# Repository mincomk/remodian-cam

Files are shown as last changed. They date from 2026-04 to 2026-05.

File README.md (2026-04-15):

# Remodian CAM

I've worked in a project called [Remodian](https://github.com/mincomk/remodian), which is a simple IR-Web bridge for Meridian speakers.

## The Problem

Previous Remodian was only capable to control the volume up and down, by one tick. So there was no way to know what the current volume level was, and it was impossible to set a specific volume level.

## My Solution
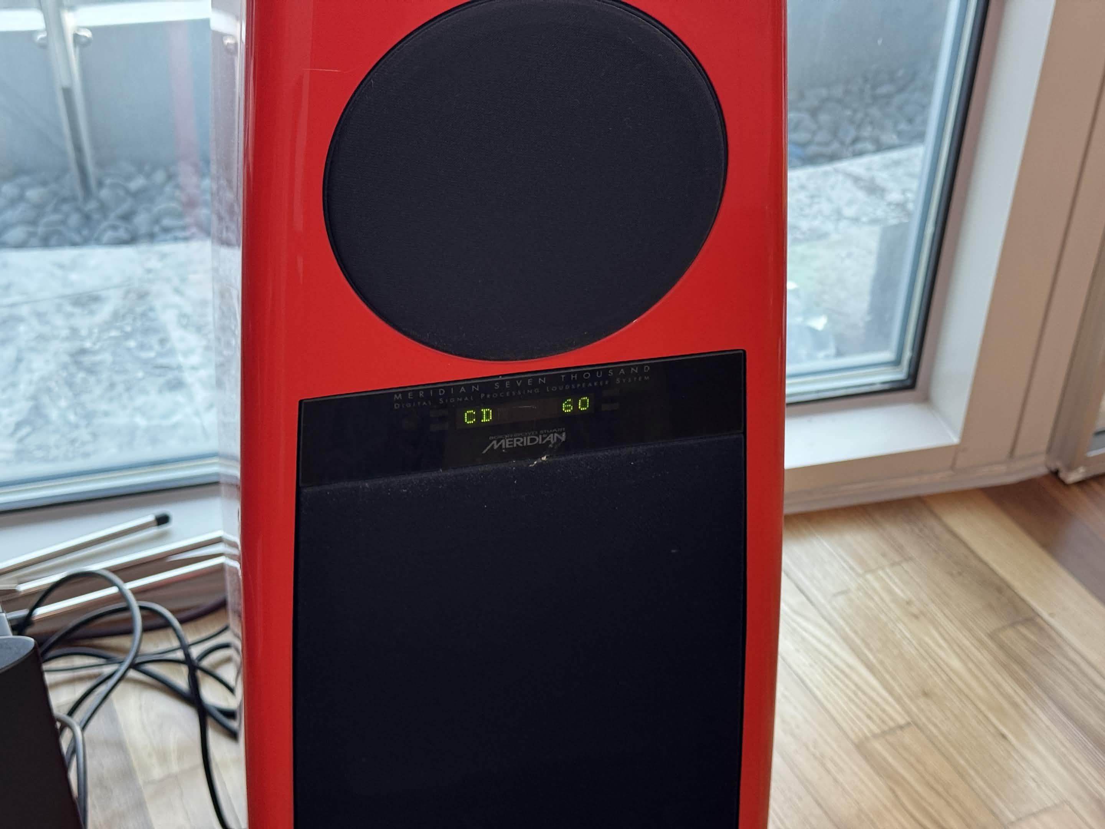
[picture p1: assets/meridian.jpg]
meridian

Unsurprisingly, the speakers have a volume display. Two green numbers showing current volume. So the next task is trivial: Computer Vision + Control System.

## Making ESP32 See the Volume
I noticed that the volume display is simple 5x7 LED grid. And the camera will always be in the same position. So I just divided the image to 5x7 regions, and averaged the pixel values in each region.

Since I could use thresholding to determine whether a region is lit or not, I went other approach: one-hot scoring. I created a template for each digit (0-9) that contains ideal state of each region (i.e. 255 for lit, 0 for unlit). Then I scored the current image against each template, and the one with the highest score is the recognized digit.

This approach avoids the need for thresholding, and is more robust to noise and lighting changes.

I've made a simple GUI tool called `calibration-ui` (`dev/calibration-ui`). This tool captures image from the camera, and allows me to configure perspective transform (i.e. warp crop) of the image. Then it produces standardized *crop string* (`1,1,1,1+1,1,1,1`) that can be used in the backend code to apply the same perspective transform.
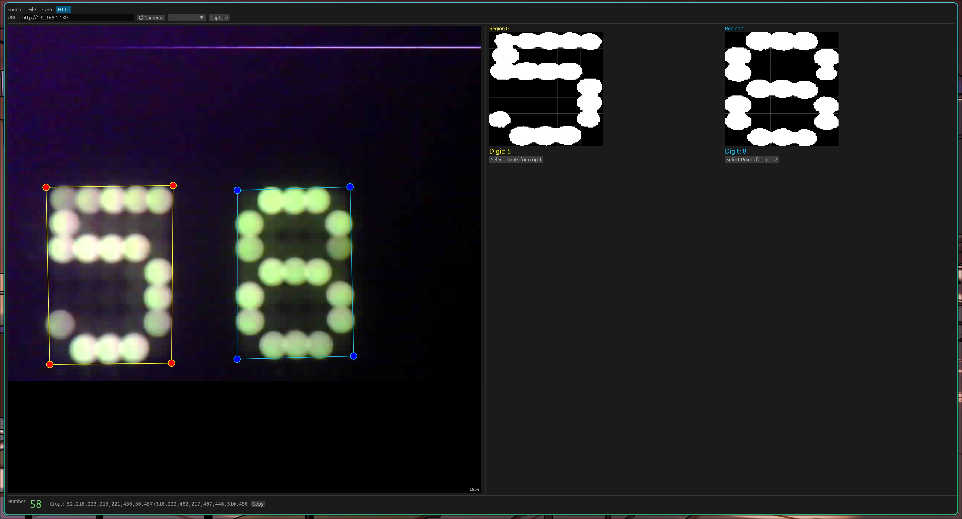
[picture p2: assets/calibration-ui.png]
calibration-ui


## Control System
ESP32 IR blaster firmware accepts four commands: `volume up`, `volume down`, `volume rapid up start`, and `volume rapid up stop`. The first two commands will send one tick of volume up/down, while the last two commands will start/stop sending volume up command repeatedly with a short delay (RC5 IR timeframe).

The control logic is based on a simple bang-bang controller. It separates the difference between current volume and target volume into three zones: **Just Right** (i.e. deadband), **Very Near** (±4.0), **Near** (±8.0), and **Far** (±∞). Depending on which zone the difference falls into, the controller will send different commands to the IR blaster.
- If the difference is in the **Just Right** zone, do nothing.
- If the difference is in the **Very Near** zone, send one tick of volume up/down in slower pace.
- If the difference is in the **Near** zone, send one tick of volume up/down in faster pace.
- If the difference is in the **Far** zone, send rapid volume up/down command.

Also I added a manual control mode, which allows the user to send volume up/down commands directly from the web interface. Web interface also does the rapid command set on long press, and stop on release.

### Problem: ESP32-CAM is slow!
ESP32-CAM is a very cheap and convenient camera module, but it has a very slow processing speed. The image processing takes around 300ms, which is too slow for control system to be responsive.

But we have a helpful trait of the volume here: It changes consistently. So I used linear extrapolation to predict the current volume level based on the last two recognized volume levels and their timestamps. This way, we can get a more responsive control system, even with the slow image processing.

## Conclusion
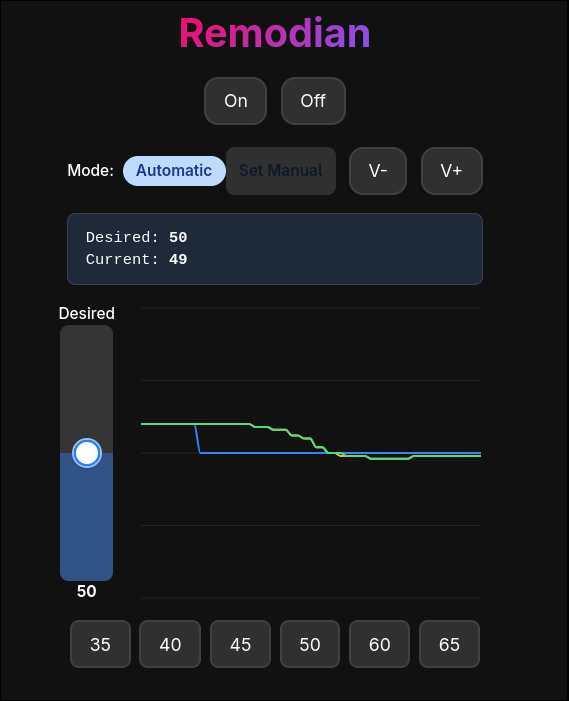
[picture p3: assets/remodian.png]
remodian


LGTM! Let's enjoy the music.

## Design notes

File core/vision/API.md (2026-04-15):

# LCD Pixel Digit Recognition API

This document describes the API for the lcd-pixel digit recognition system.

## Overview

The lcd-pixel system recognizes single digits (0-9) from LCD display images through a processing pipeline that:
1. Loads an image from disk or camera
2. Applies perspective correction to straighten the display
3. Extracts and analyzes the 5×7 segment grid
4. Matches against trained digit templates
5. Returns the detected digit or 0 if the display is empty

## Image Input

### Supported Formats

- **PNG** - Portable Network Graphics (any bit depth)
- **JPEG** - Joint Photographic Experts Group
- **Grayscale** - Single-channel images (typically pre-thresholded)
- **Color** - RGB images (green channel extracted during preprocessing)

### Image Requirements

- **Size**: Arbitrary (will be cropped and resized to 128×128)
- **Quality**: Should contain visible LCD segments
- **Color Space**: RGB or Grayscale (8-bit per channel)

### Input Interface

#### Rust API

```rust
pub trait ImageSource {
    fn width(&self) -> u32;
    fn height(&self) -> u32;
    fn pixel_rgb(&self, x: u32, y: u32) -> (f32, f32, f32);
}
```

**Example: File-based Input**

```rust
use lcd_pixel::preprocess::FileImageSource;

let source = FileImageSource::new("path/to/image.jpg")?;
```

**Future: Camera Input**

The `ImageSource` trait enables camera integration without modifying core code:

```rust
pub struct Ov2640Source {
    buffer: Vec<u8>,
    width: u32,
    height: u32,
}

impl ImageSource for Ov2640Source {
    fn width(&self) -> u32 { self.width }
    fn height(&self) -> u32 { self.height }
    fn pixel_rgb(&self, x: u32, y: u32) -> (f32, f32, f32) {
        // Decode from raw camera buffer
        // Return normalized (r, g, b) in [0.0, 1.0]
    }
}
```

## Crop Points Input

### Purpose

Four perspective corner points define the LCD display region within the image and correct for skew/tilt.

### Format

```
[(u32, u32); 4]
```

Four `(x, y)` coordinate pairs in the **source image coordinate system**.

### Point Order

Points must be provided in a specific order:
1. **Top-left** — upper-left corner of display
2. **Top-right** — upper-right corner of display
3. **Bottom-right** — lower-right corner of display
4. **Bottom-left** — lower-left corner of display

```
(0,0)              (127,0)
  +------------------+
  |  L C D D I S P   |
  |                  |
  +------------------+
(0,127)          (127,127)
```

### Coordinate System

- **Origin**: Top-left of the source image (0, 0)
- **X-axis**: Increases left to right
- **Y-axis**: Increases top to bottom
- **Range**: [0, image_width) × [0, image_height)

### Identity Transform (No Correction)

For an already-straight 128×128 image:

```rust
let points = [(0, 0), (127, 0), (127, 127), (0, 127)];
```

### Perspective Correction

For a tilted or skewed display, provide the actual corner positions:

```rust
// Display tilted right, bottom-right corner shifted out
let points = [(10, 5), (120, 2), (125, 135), (5, 130)];
```

## Processing Pipeline

### Steps

1. **Extract Green Channel** — RGB images are reduced to green channel for better LCD contrast
2. **Crop to Bounding Box** — Axis-aligned bbox of 4 points is cropped for efficiency
3. **Perspective Warp** — Homography transform maps points to 128×128 output
4. **Threshold** — Binary thresholding at 195/255 ≈ 0.765 (Otsu's method available)
5. **Cell Extraction** — 128×128 image divided into 5-wide × 7-tall grid, cells averaged
6. **Template Matching** — Cells scored against 10 digit templates (0-9)
7. **Empty Detection** — If mean brightness < 0.05, display is considered off/empty

## Output Format

### Return Type

```rust
pub fn get_digit(templates: &[[bool; 35]; 10], cells: &[f32; 35]) -> Option<u8>
```

**Returns:**
- `Some(digit)` — Detected digit (0-9)
- `None` — Display is empty/off (output as 0)

### Output Values

| Value | Meaning |
|---|---|
| 0 | Empty display or digit 0 |
| 1-9 | Detected digit |

### Command-Line Binary

```
$ lcd-pixel <image> <x1> <y1> <x2> <y2> <x3> <y3> <x4> <y4>
Digit: N
```

**Exit Codes:**
- `0` — Successful detection
- `1` — Error (missing arguments, invalid file, invalid coordinates)

### Detection Details

The `get_digit()` function performs **off-pixel scoring**:

```
score = Σ(cells[i] if template[i] is ON)
      - Σ(cells[i] if template[i] is OFF)
```

This rewards matching ON segments and penalizes unwanted brightness in OFF segments, improving accuracy.

## Usage Examples

### Rust Library

```rust
use lcd_pixel::preprocess::{preprocess, FileImageSource};
use lcd_pixel::detect::{calc::get_digit, template::load_templates};

// Load image
let source = FileImageSource::new("display.jpg")?;

// Define display region (e.g., known corners)
let points = [(20, 15), (480, 10), (490, 220), (15, 225)];

// Run pipeline
let sample = preprocess(&source, points);
let cells = sample.extract_cells();
let templates = load_templates();

// Detect digit
match get_digit(&templates, &cells) {
    Some(digit) => println!("Detected: {}", digit),
    None => println!("Display is off or empty"),
}
```

### CLI Binary

```bash
# Simple centered display (already 128×128)
./lcd-pixel display.jpg 0 0 127 0 127 127 0 127

# Tilted display in a larger photo
./lcd-pixel photo.jpg 150 100 450 95 460 310 145 315

# Grayscale pre-thresholded image
./lcd-pixel thresholded.png 0 0 127 0 127 127 0 127
```

## Error Handling

### File Loading

```
Failed to load image 'path.jpg': Format error decoding Jpeg: ...
```

**Causes:**
- File doesn't exist
- Unsupported image format
- Corrupted image data

### Invalid Coordinates

```
Invalid coordinate: 999999999999
```

**Causes:**
- Non-integer input
- Exceeds u32 range

## Performance Characteristics

| Operation | Time | Notes |
|---|---|---|
| Image loading | ~10-50ms | Depends on file size and format |
| Green channel extraction | ~5-20ms | O(width × height) |
| Perspective warp | ~50-100ms | 128×128 output with homography |
| Cell extraction | <1ms | Fixed 5×7 grid on 128×128 |
| Template matching | <1ms | 10 templates, 35 cells each |
| **Total** | ~100-200ms | Per image |

## Future Extensions

### Camera Support

Implement `ImageSource` for OV2640 or similar:
```rust
pub struct Ov2640Source { ... }
impl ImageSource for Ov2640Source { ... }
```

No pipeline changes needed—fully backward compatible.

### Confidence Scoring

Return top-N matches with scores:
```rust
pub fn get_digit_ranked(
    templates: &[[bool; 35]; 10], 
    cells: &[f32; 35]
) -> Vec<(u8, f32)>
```

### Multi-Digit Recognition

Process multiple displays by providing multiple point sets:
```rust
let displays = vec![points1, points2, points3];
for points in displays {
    let sample = preprocess(&source, points);
    let digit = get_digit(&templates, &sample.extract_cells());
}
```

### Adaptive Thresholding

Already implemented—use `compute_otsu_threshold()` instead of fixed 195:
```rust
let threshold = compute_otsu_threshold(&warped);
let thresholded = threshold(&warped, threshold);
```

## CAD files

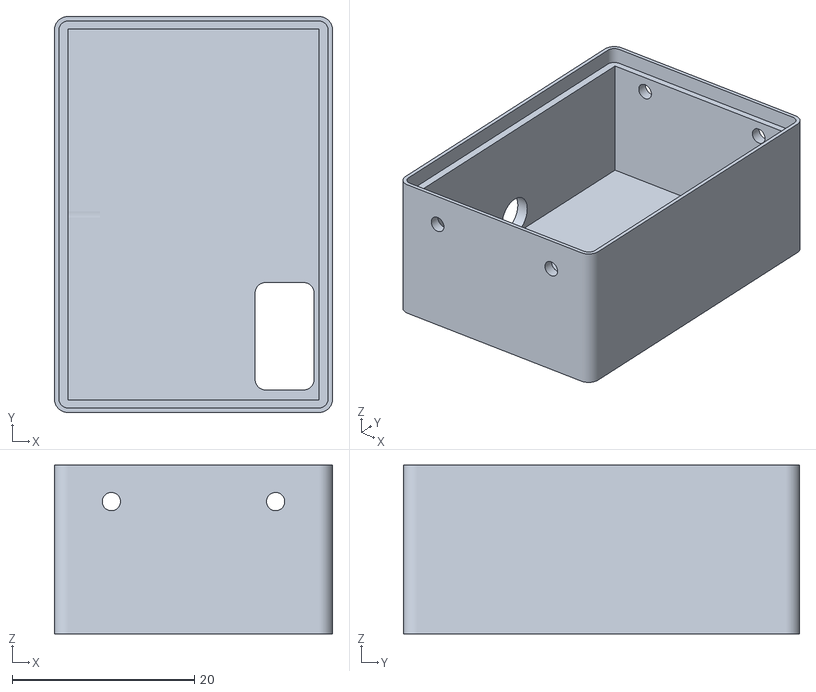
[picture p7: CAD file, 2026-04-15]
casing/mesh/bottom-bottom.stl
30.5 x 43.4 x 18.5

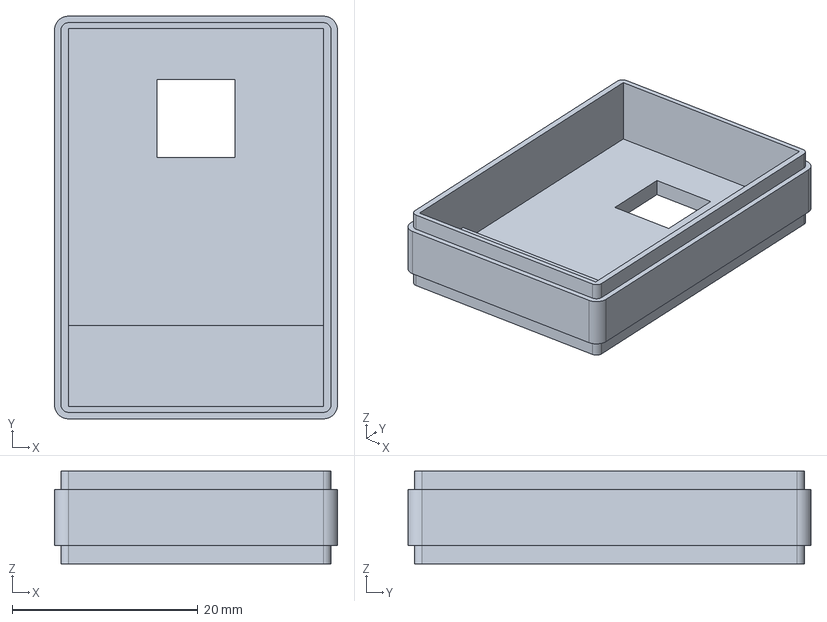
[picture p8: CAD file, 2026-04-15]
casing/top.FCStd
30.5 x 43.4 x 10.0 mm

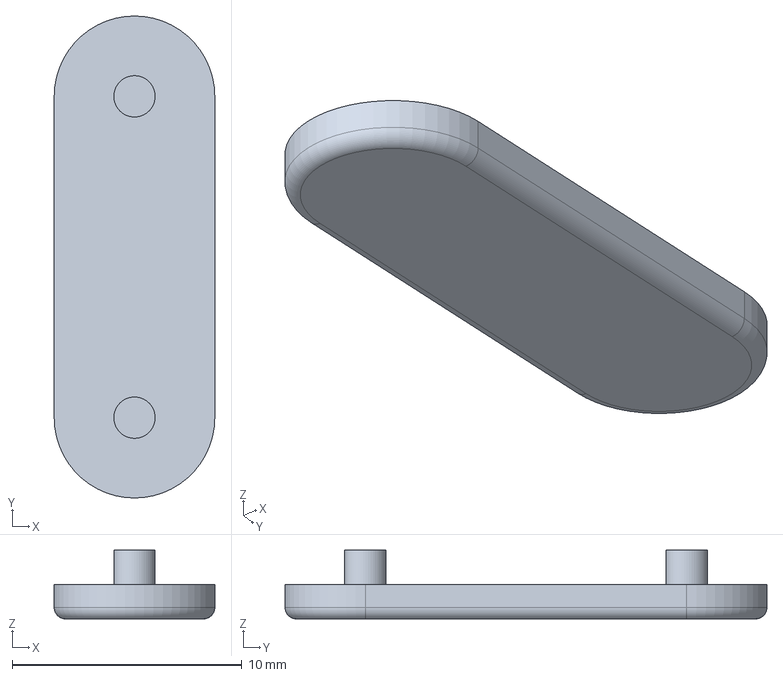
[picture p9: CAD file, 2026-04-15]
casing/connector.FCStd
7.00 x 21.0 x 3.00 mm

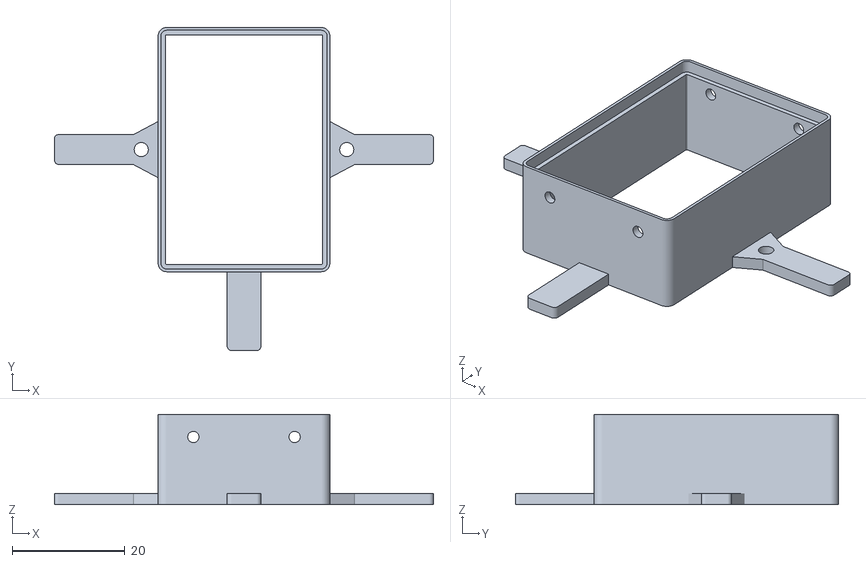
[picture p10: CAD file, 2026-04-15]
casing/mesh/guard-guard.stl
67.3 x 57.4 x 16.0

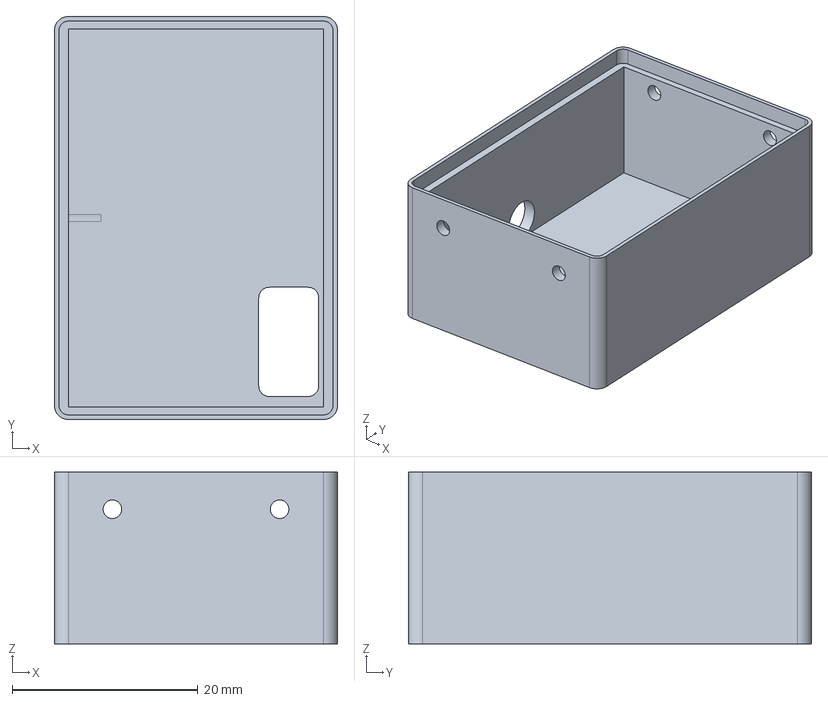
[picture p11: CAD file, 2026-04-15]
casing/bottom.FCStd
30.5 x 43.4 x 18.5 mm

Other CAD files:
casing/guard.FCStd
casing/mesh/top-Body.stl
casing/mesh/top-Top.stl
casing/mesh/connector-connector.stl

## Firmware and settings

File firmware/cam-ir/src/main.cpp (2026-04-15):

#include <Arduino.h>
#include <WiFi.h>
#include <WebServer.h>
#include "esp_camera.h"
#include <IRremoteESP8266.h>
#include <IRsend.h>

// ── WiFi credentials ──────────────────────────────────────────────────────────
#define WIFI_SSID "wlo1"
#define WIFI_PASS "haskell1234"

// ── AI-Thinker ESP32-CAM pin map ──────────────────────────────────────────────
#define CAM_PIN_PWDN    32
#define CAM_PIN_RESET   -1
#define CAM_PIN_XCLK     0
#define CAM_PIN_SIOD    26
#define CAM_PIN_SIOC    27
#define CAM_PIN_D7      35
#define CAM_PIN_D6      34
#define CAM_PIN_D5      39
#define CAM_PIN_D4      36
#define CAM_PIN_D3      21
#define CAM_PIN_D2      19
#define CAM_PIN_D1      18
#define CAM_PIN_D0       5
#define CAM_PIN_VSYNC   25
#define CAM_PIN_HREF    23
#define CAM_PIN_PCLK    22

// ── IR transmitter ────────────────────────────────────────────────────────────
#define IR_TX_PIN 12  // GPIO12 — SD_DATA2, free when SD card unused

IRsend ir(IR_TX_PIN);

// ── IR command queue and synchronization ──────────────────────────────────────
struct IRCommand {
    uint8_t addr;
    uint8_t cmd;
    bool    toggle;
};

static SemaphoreHandle_t irMutex        = nullptr;
static QueueHandle_t     irOneShotQueue = nullptr;

static bool    irContinuous = false;
static uint8_t irContAddr   = 0;
static uint8_t irContCmd    = 0;
static bool    irContToggle = false;

WebServer server(80);

// ── Camera init ───────────────────────────────────────────────────────────────
static bool initCamera() {
    camera_config_t config;
    config.ledc_channel = LEDC_CHANNEL_0;
    config.ledc_timer   = LEDC_TIMER_0;
    config.pin_d0       = CAM_PIN_D0;
    config.pin_d1       = CAM_PIN_D1;
    config.pin_d2       = CAM_PIN_D2;
    config.pin_d3       = CAM_PIN_D3;
    config.pin_d4       = CAM_PIN_D4;
    config.pin_d5       = CAM_PIN_D5;
    config.pin_d6       = CAM_PIN_D6;
    config.pin_d7       = CAM_PIN_D7;
    config.pin_xclk     = CAM_PIN_XCLK;
    config.pin_pclk     = CAM_PIN_PCLK;
    config.pin_vsync    = CAM_PIN_VSYNC;
    config.pin_href     = CAM_PIN_HREF;
    config.pin_sscb_sda = CAM_PIN_SIOD;
    config.pin_sscb_scl = CAM_PIN_SIOC;
    config.pin_pwdn     = CAM_PIN_PWDN;
    config.pin_reset    = CAM_PIN_RESET;
    config.xclk_freq_hz = 10000000;
    config.pixel_format = PIXFORMAT_JPEG;

    if (psramFound()) {
        config.frame_size   = FRAMESIZE_VGA;    // 640×480 — fast over WiFi
        config.jpeg_quality = 20;               // 0–63, lower = better
        config.fb_count     = 2;
    } else {
        config.frame_size   = FRAMESIZE_SVGA;   // 800×600
        config.jpeg_quality = 20;
        config.fb_count     = 1;
    }

    esp_err_t err = esp_camera_init(&config);
    if (err != ESP_OK) {
        Serial.printf("Camera init failed: 0x%x\n", err);
        return false;
    }
    return true;
}

// ── Route: GET /capture ───────────────────────────────────────────────────────
void handleCapture() {
    camera_fb_t *fb = esp_camera_fb_get();
    if (!fb) {
        server.send(500, "text/plain", "Camera capture failed");
        return;
    }

    server.sendHeader("Cache-Control", "no-store");
    server.sendHeader("Content-Disposition", "inline; filename=capture.jpg");
    server.sendHeader("Content-Length", String(fb->len));
    server.send_P(200, "image/jpeg",
                  reinterpret_cast<const char*>(fb->buf),
                  fb->len);

    esp_camera_fb_return(fb);
}

// ── Route: POST /ir ───────────────────────────────────────────────────────────
// Params: address (0-31), command (0-127), toggle (0|1), signal (1|2|3)
// signal 1 = single fire (enqueued), 2 = start continuous, 3 = stop
void handleIR() {
    if (!server.hasArg("address") || !server.hasArg("command") ||
        !server.hasArg("toggle")  || !server.hasArg("signal")) {
        server.send(400, "text/plain", "Missing params: address,command,toggle,signal");
        return;
    }

    uint8_t address = (uint8_t)server.arg("address").toInt();
    uint8_t command = (uint8_t)server.arg("command").toInt();
    bool    toggle  = server.arg("toggle").toInt() != 0;
    uint8_t signal  = (uint8_t)server.arg("signal").toInt();

    Serial.printf("[IR] addr=%u cmd=%u toggle=%u signal=%u\n",
                  address, command, (uint8_t)toggle, signal);

    switch (signal) {
        case 1: {
            IRCommand cmd = {address, command, toggle};
            if (xQueueSend(irOneShotQueue, &cmd, 0) == pdTRUE) {
                Serial.println("[IR] single fire enqueued");
            } else {
                Serial.println("[IR] single fire dropped (queue full)");
            }
            server.send(200, "text/plain", "ok");
            break;
        }
        case 2:
            if (xSemaphoreTake(irMutex, pdMS_TO_TICKS(10)) == pdTRUE) {
                irContAddr   = address;
                irContCmd    = command;
                irContToggle = toggle;
                irContinuous = true;
                xSemaphoreGive(irMutex);
                Serial.println("[IR] continuous start");
            } else {
                Serial.println("[IR] continuous start failed (mutex timeout)");
            }
            server.send(200, "text/plain", "ok");
            break;
        case 3:
            if (xSemaphoreTake(irMutex, pdMS_TO_TICKS(10)) == pdTRUE) {
                irContinuous = false;
                xSemaphoreGive(irMutex);
                Serial.println("[IR] continuous stop");
            } else {
                Serial.println("[IR] continuous stop failed (mutex timeout)");
            }
            server.send(200, "text/plain", "ok");
            break;
        default:
            server.send(400, "text/plain", "Invalid signal value (use 1, 2, or 3)");
    }
}

// ── Route: GET /ir/test — blink IR pin 5× at ~10 Hz to verify hardware ───────
// Visible as flicker on a phone camera (IR appears purple/white).
void handleIRTest() {
    Serial.printf("[IR] hardware test on GPIO%d\n", IR_TX_PIN);

    // Pause IR continuous mode and flush one-shot queue during test
    if (xSemaphoreTake(irMutex, pdMS_TO_TICKS(10)) == pdTRUE) {
        irContinuous = false;
        xQueueReset(irOneShotQueue);
        xSemaphoreGive(irMutex);
    }

    for (int i = 0; i < 5; i++) {
        digitalWrite(IR_TX_PIN, HIGH);
        vTaskDelay(pdMS_TO_TICKS(50));
        digitalWrite(IR_TX_PIN, LOW);
        vTaskDelay(pdMS_TO_TICKS(50));
    }
    server.send(200, "text/plain", "IR pin blink done — check phone camera for purple flashes on GPIO" + String(IR_TX_PIN));
}

// ── Route: GET / (simple info page) ──────────────────────────────────────────
void handleRoot() {
    server.send(200, "text/html",
        "<h1>ESP32-CAM</h1>"
        "<p><a href='/capture'>GET /capture</a> — returns a JPEG image</p>");
}

// ── IR task — Core 0, handles all IR transmission ─────────────────────────────
void irTask(void *pvParameters) {
    TickType_t xLastWakeTime = xTaskGetTickCount();

    for (;;) {
        // Check for one-shot IR command
        IRCommand oneShot;
        if (xQueueReceive(irOneShotQueue, &oneShot, 0) == pdTRUE) {
            ir.sendRC5(ir.encodeRC5X(oneShot.addr, oneShot.cmd, oneShot.toggle));
        }

        // Check and handle continuous IR mode
        bool doSend = false;
        uint8_t addr, cmd;
        bool tog;

        if (xSemaphoreTake(irMutex, pdMS_TO_TICKS(5)) == pdTRUE) {
            if (irContinuous) {
                doSend = true;
                addr = irContAddr;
                cmd = irContCmd;
                tog = irContToggle;
            }
            xSemaphoreGive(irMutex);
        }

        if (doSend) {
            ir.sendRC5(ir.encodeRC5X(addr, cmd, tog));
        }

        // Delay until next 117ms period
        xTaskDelayUntil(&xLastWakeTime, pdMS_TO_TICKS(117));
    }
}

// ── HTTP task — Core 1, handles all HTTP serving ────────────────────────────
void httpTask(void *pvParameters) {
    for (;;) {
        server.handleClient();
        vTaskDelay(pdMS_TO_TICKS(1));  // Yield to prevent WDT starvation
    }
}

// ── Setup ─────────────────────────────────────────────────────────────────────
void setup() {
    Serial.begin(115200);

    if (!initCamera()) {
        Serial.println("Halting — camera failed.");
        while (true) delay(1000);
    }
    Serial.println("Camera ready.");

    WiFi.begin(WIFI_SSID, WIFI_PASS);
    Serial.print("Connecting to WiFi");
    while (WiFi.status() != WL_CONNECTED) {
        delay(500);
        Serial.print('.');
    }
    ir.begin();
    server.on("/", HTTP_GET, handleRoot);
    server.on("/capture", HTTP_GET, handleCapture);
    server.on("/ir", HTTP_POST, handleIR);
    server.on("/ir/test", HTTP_GET, handleIRTest);
    server.begin();
    Serial.printf("\nHTTP server started. Board IP: http://%s\n", WiFi.localIP().toString().c_str());

    // Create FreeRTOS synchronization primitives
    irMutex = xSemaphoreCreateMutex();
    irOneShotQueue = xQueueCreate(2, sizeof(IRCommand));

    if (irMutex == nullptr || irOneShotQueue == nullptr) {
        Serial.println("ERROR: Failed to create IR synchronization primitives!");
        return;
    }

    // Launch IR task on Core 0
    xTaskCreatePinnedToCore(
        irTask,
        "irTask",
        4096,
        nullptr,
        2,
        nullptr,
        0
    );

    // Launch HTTP task on Core 1
    xTaskCreatePinnedToCore(
        httpTask,
        "httpTask",
        8192,
        nullptr,
        1,
        nullptr,
        1
    );

    Serial.println("FreeRTOS tasks created: irTask on Core 0, httpTask on Core 1");
}

// ── Loop ──────────────────────────────────────────────────────────────────────
// Tasks are now handled by irTask (Core 0) and httpTask (Core 1).
// This loop task is suspended and yields to prevent watchdog timer starvation.
void loop() {
    vTaskDelay(portMAX_DELAY);
}

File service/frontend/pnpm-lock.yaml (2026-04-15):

lockfileVersion: '9.0'

settings:
  autoInstallPeers: true
  excludeLinksFromLockfile: false

importers:

  .:
    dependencies:
      '@headlessui/react':
        specifier: ^2.2.9
        version: 2.2.9(react-dom@19.2.0(react@19.2.0))(react@19.2.0)
      '@heroicons/react':
        specifier: ^2.2.0
        version: 2.2.0(react@19.2.0)
      '@tailwindcss/vite':
        specifier: ^4.1.16
        version: 4.1.16(vite@7.1.12(@types/node@24.9.2)(jiti@2.6.1)(lightningcss@1.30.2)(terser@5.44.0))
      react:
        specifier: ^19.1.1
        version: 19.2.0
      react-dom:
        specifier: ^19.1.1
        version: 19.2.0(react@19.2.0)
      recharts:
        specifier: ^3.8.1
        version: 3.8.1(@types/react@19.2.2)(react-dom@19.2.0(react@19.2.0))(react-is@19.2.5)(react@19.2.0)(redux@5.0.1)
    devDependencies:
      '@eslint/js':
        specifier: ^9.36.0
        version: 9.39.0
      '@tailwindcss/postcss':
        specifier: ^4.1.16
        version: 4.1.16
      '@types/node':
        specifier: ^24.6.0
        version: 24.9.2
      '@types/react':
        specifier: ^19.1.16
        version: 19.2.2
      '@types/react-dom':
        specifier: ^19.1.9
        version: 19.2.2(@types/react@19.2.2)
      '@vitejs/plugin-react':
        specifier: ^5.0.4
        version: 5.1.0(vite@7.1.12(@types/node@24.9.2)(jiti@2.6.1)(lightningcss@1.30.2)(terser@5.44.0))
      autoprefixer:
        specifier: ^10.4.21
        version: 10.4.21(postcss@8.5.6)
      eslint:
        specifier: ^9.36.0
        version: 9.39.0(jiti@2.6.1)
      eslint-plugin-react-hooks:
        specifier: ^5.2.0
        version: 5.2.0(eslint@9.39.0(jiti@2.6.1))
      eslint-plugin-react-refresh:
        specifier: ^0.4.22
        version: 0.4.24(eslint@9.39.0(jiti@2.6.1))
      globals:
        specifier: ^16.4.0
        version: 16.5.0
      postcss:
        specifier: ^8.5.6
        version: 8.5.6
      prettier:
        specifier: 3.6.2
        version: 3.6.2
      tailwindcss:
        specifier: ^4.1.16
        version: 4.1.16
      typescript:
        specifier: ~5.9.3
        version: 5.9.3
      typescript-eslint:
        specifier: ^8.45.0
        version: 8.46.2(eslint@9.39.0(jiti@2.6.1))(typescript@5.9.3)
      vite:
        specifier: ^7.1.7
        version: 7.1.12(@types/node@24.9.2)(jiti@2.6.1)(lightningcss@1.30.2)(terser@5.44.0)
      vite-plugin-pwa:
        specifier: ^1.1.0
        version: 1.1.0(vite@7.1.12(@types/node@24.9.2)(jiti@2.6.1)(lightningcss@1.30.2)(terser@5.44.0))(workbox-build@7.3.0(@types/babel__core@7.20.5))(workbox-window@7.3.0)

packages:

  '@alloc/quick-lru@5.2.0':
    resolution: {integrity: sha512-UrcABB+4bUrFABwbluTIBErXwvbsU/V7TZWfmbgJfbkwiBuziS9gxdODUyuiecfdGQ85jglMW6juS3+z5TsKLw==}
    engines: {node: '>=10'}

  '@apideck/better-ajv-errors@0.3.6':
    resolution: {integrity: sha512-P+ZygBLZtkp0qqOAJJVX4oX/sFo5JR3eBWwwuqHHhK0GIgQOKWrAfiAaWX0aArHkRWHMuggFEgAZNxVPwPZYaA==}
    engines: {node: '>=10'}
    peerDependencies:
      ajv: '>=8'

  '@babel/code-frame@7.27.1':
    resolution: {integrity: sha512-cjQ7ZlQ0Mv3b47hABuTevyTuYN4i+loJKGeV9flcCgIK37cCXRh+L1bd3iBHlynerhQ7BhCkn2BPbQUL+rGqFg==}
    engines: {node: '>=6.9.0'}

  '@babel/compat-data@7.28.5':
    resolution: {integrity: sha512-6uFXyCayocRbqhZOB+6XcuZbkMNimwfVGFji8CTZnCzOHVGvDqzvitu1re2AU5LROliz7eQPhB8CpAMvnx9EjA==}
    engines: {node: '>=6.9.0'}

  '@babel/core@7.28.5':
    resolution: {integrity: sha512-e7jT4DxYvIDLk1ZHmU/m/mB19rex9sv0c2ftBtjSBv+kVM/902eh0fINUzD7UwLLNR+jU585GxUJ8/EBfAM5fw==}
    engines: {node: '>=6.9.0'}

  '@babel/generator@7.28.5':
    resolution: {integrity: sha512-3EwLFhZ38J4VyIP6WNtt2kUdW9dokXA9Cr4IVIFHuCpZ3H8/YFOl5JjZHisrn1fATPBmKKqXzDFvh9fUwHz6CQ==}
    engines: {node: '>=6.9.0'}

  '@babel/helper-annotate-as-pure@7.27.3':
    resolution: {integrity: sha512-fXSwMQqitTGeHLBC08Eq5yXz2m37E4pJX1qAU1+2cNedz/ifv/bVXft90VeSav5nFO61EcNgwr0aJxbyPaWBPg==}
    engines: {node: '>=6.9.0'}

  '@babel/helper-compilation-targets@7.27.2':
    resolution: {integrity: sha512-2+1thGUUWWjLTYTHZWK1n8Yga0ijBz1XAhUXcKy81rd5g6yh7hGqMp45v7cadSbEHc9G3OTv45SyneRN3ps4DQ==}
    engines: {node: '>=6.9.0'}

  '@babel/helper-create-class-features-plugin@7.28.5':
    resolution: {integrity: sha512-q3WC4JfdODypvxArsJQROfupPBq9+lMwjKq7C33GhbFYJsufD0yd/ziwD+hJucLeWsnFPWZjsU2DNFqBPE7jwQ==}
    engines: {node: '>=6.9.0'}
    peerDependencies:
      '@babel/core': ^7.0.0

  '@babel/helper-create-regexp-features-plugin@7.28.5':
    resolution: {integrity: sha512-N1EhvLtHzOvj7QQOUCCS3NrPJP8c5W6ZXCHDn7Yialuy1iu4r5EmIYkXlKNqT99Ciw+W0mDqWoR6HWMZlFP3hw==}
    engines: {node: '>=6.9.0'}
    peerDependencies:
      '@babel/core': ^7.0.0

  '@babel/helper-define-polyfill-provider@0.6.5':
    resolution: {integrity: sha512-uJnGFcPsWQK8fvjgGP5LZUZZsYGIoPeRjSF5PGwrelYgq7Q15/Ft9NGFp1zglwgIv//W0uG4BevRuSJRyylZPg==}
    peerDependencies:
      '@babel/core': ^7.4.0 || ^8.0.0-0 <8.0.0
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

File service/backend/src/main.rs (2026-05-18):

use std::convert::Infallible;
use std::sync::{
    Arc,
    atomic::{AtomicU32, AtomicBool, Ordering},
};
use std::time::Duration;

use axum::{
    Json, Router,
    extract::State,
    response::sse::{Event, KeepAlive, Sse},
    routing::{get, post},
};
use parking_lot::Mutex;
use remodian_client::{Command, MqttRemodianClient, RemodianClient};
use remodian_control::{
    AnyClient, UdpRemodianClient, VolumeState, control_loop, fetch_volume_task,
};
use serde::{Deserialize, Serialize};
use tokio::sync::broadcast;
use tokio_stream::StreamExt as _;
use tokio_stream::wrappers::BroadcastStream;
use tower_http::cors::CorsLayer;

// ── CLI ───────────────────────────────────────────────────────────────────────

#[derive(clap::Parser)]
struct Cli {
    /// Crop spec passed to compvis-engine, e.g. "10,20,30,40+50,60,70,80".
    /// Also configurable via CROP env var.
    #[clap(long, env = "CROP")]
    crop: String,

    #[clap(long, env = "CAM_URL")]
    cam_url: Option<String>,

    /// UDP socket address of the IR device (e.g. 192.168.1.60:5555).
    #[clap(long, env = "IR_UDP")]
    ir_udp: Option<String>,

    /// Port to listen on (default: 3000).
    /// Also configurable via PORT env var.
    #[clap(long, env = "PORT", default_value = "3000")]
    port: u16,
}

// ── Shared state ──────────────────────────────────────────────────────────────

struct AppState {
    volume_state: Arc<Mutex<VolumeState>>,
    desired_volume: Arc<AtomicU32>,
    is_automatic: Arc<AtomicBool>,
    client: Arc<AnyClient>,
    sse_tx: broadcast::Sender<String>,
}

// ── Serialization types ───────────────────────────────────────────────────────

#[derive(Serialize)]
struct VolumeSnapshot {
    current: u32,
    expected: u32,
    desired: u32,
    off: bool,
    automatic: bool,
}

#[derive(Deserialize)]
struct SetVolumeBody {
    volume: u32,
}

// ── Handlers ──────────────────────────────────────────────────────────────────

async fn get_volume(State(state): State<Arc<AppState>>) -> Json<VolumeSnapshot> {
    Json(read_snapshot(&state))
}

async fn sse_handler(
    State(state): State<Arc<AppState>>,
) -> Sse<impl tokio_stream::Stream<Item = Result<Event, Infallible>>> {
    let rx = state.sse_tx.subscribe();
    let stream = BroadcastStream::new(rx)
        .filter_map(|msg| msg.ok().map(|data| Ok(Event::default().data(data))));
    Sse::new(stream).keep_alive(KeepAlive::default())
}

async fn set_volume(
    State(state): State<Arc<AppState>>,
    Json(body): Json<SetVolumeBody>,
) -> axum::http::StatusCode {
    state.desired_volume.store(body.volume, Ordering::Relaxed);
    state.is_automatic.store(true, Ordering::Relaxed);
    axum::http::StatusCode::NO_CONTENT
}

async fn volume_up(State(state): State<Arc<AppState>>) -> axum::http::StatusCode {
    state.is_automatic.store(false, Ordering::Relaxed);
    if let Err(e) = state.client.vol_up().await {
        eprintln!("volume_up error: {e}");
        return axum::http::StatusCode::INTERNAL_SERVER_ERROR;
    }
    axum::http::StatusCode::NO_CONTENT
}

async fn volume_down(State(state): State<Arc<AppState>>) -> axum::http::StatusCode {
    state.is_automatic.store(false, Ordering::Relaxed);
    if let Err(e) = state.client.vol_down().await {
        eprintln!("volume_down error: {e}");
        return axum::http::StatusCode::INTERNAL_SERVER_ERROR;
    }
    axum::http::StatusCode::NO_CONTENT
}

async fn rapid_up(State(state): State<Arc<AppState>>) -> axum::http::StatusCode {
    state.is_automatic.store(false, Ordering::Relaxed);
    if let Err(e) = state.client.start(Command::VolUp).await {
        eprintln!("rapid_up error: {e}");
        return axum::http::StatusCode::INTERNAL_SERVER_ERROR;
    }
    axum::http::StatusCode::NO_CONTENT
}

async fn rapid_down(State(state): State<Arc<AppState>>) -> axum::http::StatusCode {
    state.is_automatic.store(false, Ordering::Relaxed);
    if let Err(e) = state.client.start(Command::VolDown).await {
        eprintln!("rapid_down error: {e}");
        return axum::http::StatusCode::INTERNAL_SERVER_ERROR;
    }
    axum::http::StatusCode::NO_CONTENT
}

async fn rapid_stop(State(state): State<Arc<AppState>>) -> axum::http::StatusCode {
    if let Err(e) = state.client.stop().await {
        eprintln!("rapid_stop error: {e}");
        return axum::http::StatusCode::INTERNAL_SERVER_ERROR;
    }
    axum::http::StatusCode::NO_CONTENT
}

async fn power_on(State(state): State<Arc<AppState>>) -> axum::http::StatusCode {
    state.is_automatic.store(false, Ordering::Relaxed);
    if let Err(e) = state.client.cd_on().await {
        eprintln!("power_on error: {e}");
        return axum::http::StatusCode::INTERNAL_SERVER_ERROR;
    }
    axum::http::StatusCode::NO_CONTENT
}

async fn power_off(State(state): State<Arc<AppState>>) -> axum::http::StatusCode {
    state.is_automatic.store(false, Ordering::Relaxed);
    if let Err(e) = state.client.off().await {
        eprintln!("power_off error: {e}");
        return axum::http::StatusCode::INTERNAL_SERVER_ERROR;
    }
    axum::http::StatusCode::NO_CONTENT
}

async fn set_manual(State(state): State<Arc<AppState>>) -> axum::http::StatusCode {
    state.is_automatic.store(false, Ordering::Relaxed);
    axum::http::StatusCode::NO_CONTENT
}

// ── Helpers ───────────────────────────────────────────────────────────────────

fn read_snapshot(state: &AppState) -> VolumeSnapshot {
    let (current, expected, is_off) = {
        let vs = state.volume_state.lock();
        (vs.volume, vs.expected_volume(), vs.is_off)
    };
    let desired = state.desired_volume.load(Ordering::Relaxed);
    let automatic = state.is_automatic.load(Ordering::Relaxed);
    VolumeSnapshot {
        current,
        expected,
        desired,
        off: is_off,
        automatic,
    }
}

// ── Main ──────────────────────────────────────────────────────────────────────
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
